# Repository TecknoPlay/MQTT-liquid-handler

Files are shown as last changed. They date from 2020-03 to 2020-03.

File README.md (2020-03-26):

MQTT-liquid-handler
=====
**3D printed and remotely controllable liquid handler (peristaltic pump and syringe)**
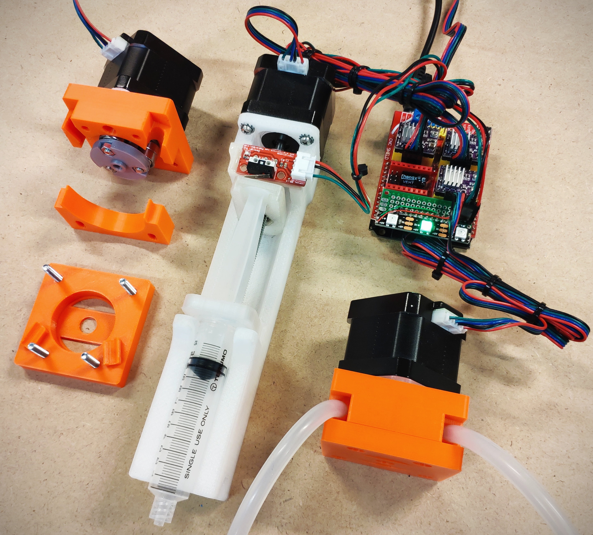
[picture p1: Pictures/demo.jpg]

**Price : around 50€-75€**

Material 
-----
### Electronic 
- ESP32 UNO [Aliexpress](https://www.aliexpress.com/item/32839196190.html) [Amazon](https://www.amazon.fr/ESP32-Carte-Bluetooth-ESP-32-ESP32S/dp/B07FS8FV1K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) 
- Arduino UNO CNC shield (with DRV8825) [Aliexpress](https://www.aliexpress.com/item/32808956717.html) [Amazon](https://www.amazon.fr/dp/B082Y4B6HC/)
- Nema17 [Aliexpress](https://www.aliexpress.com/item/32376023464.html) [Amazon](https://www.amazon.fr/dp/B07CZHLKTC)
- Limit switch [Aliexpress](https://www.aliexpress.com/item/32951447527.html) [Amazon](https://www.amazon.fr/dp/B073XGRRM4)
- CNC Kit [Aliexpress](https://www.aliexpress.com/item/33031649687.html) [Amazon](https://www.amazon.fr/dp/B06Y2BSCL7)
- 12V DC 5.5x2.1mm 

#### Non essential
- PCB [Aliexpress](https://www.aliexpress.com/item/32854111824.html ) 
- WS2812B RGB [Aliexpress](https://www.aliexpress.com/item/32682015405.html) 

### Screws 
**For 1 pumps and 1 syringe**
- 4X : M4 25
- 3x : M4 20
- 7X : M4 hex nuts
- 2X : M3 13
- 1X : M8 threaded rod cut to 70mm
- 1X : M8 hex nut
- 2X : M3 12
- 6x : 4x13x5mm (624ZZ) ball bearing 

Tools 
-----
### Hardware
- 3D Printer
- Phillips screwdriver
- Soldering iron
- Epoxy / glue

### Software
- Arduino IDE
- 3D printer slicer (Slic3r, Cura, ...)

**See WiKi for more instructions**

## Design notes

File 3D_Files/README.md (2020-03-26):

## Print settings
- Suggested filament : PETG (or ABS)
- Infill : 25%
- Layer height : 0.2mm
- Nozzle diameter : 0.4mm
- Support : Only for "Piston Lock" and "Rotor Base"

## Material (1 pump)
- 4X Mx X screw
- 4X Mx nut
- 2X 

## Material (1 syringe)

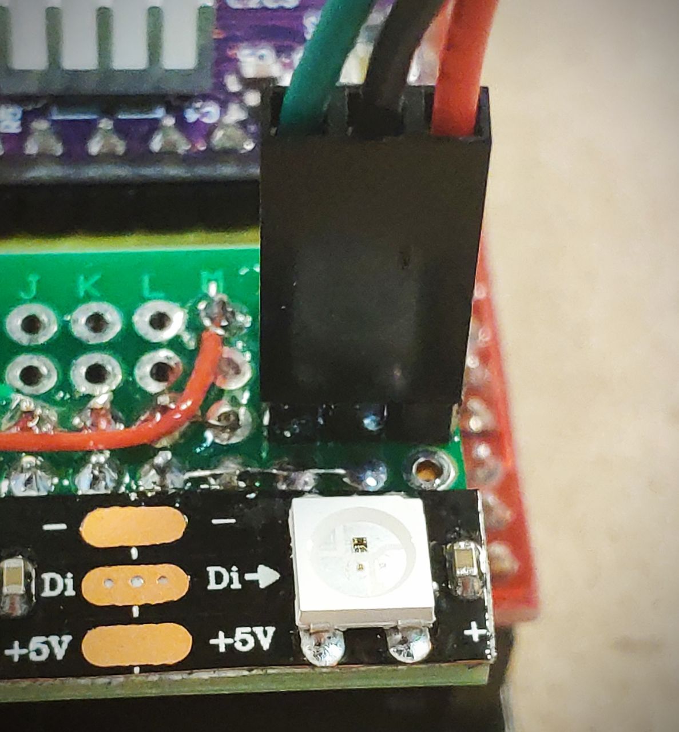
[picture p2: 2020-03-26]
Pictures/endstop_cable.jpg

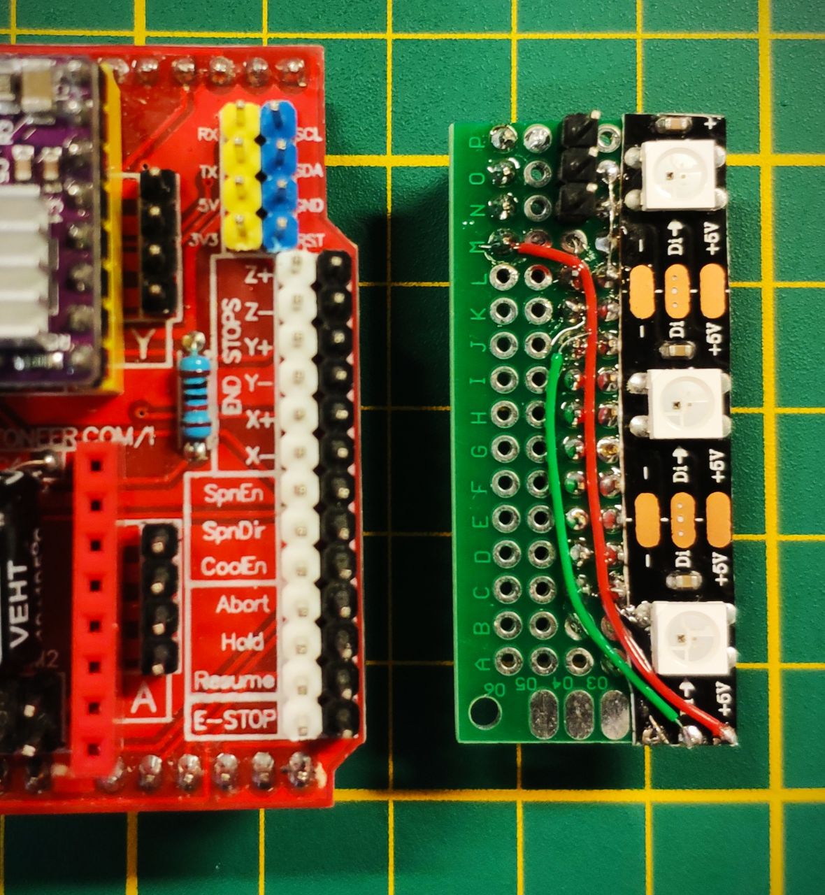
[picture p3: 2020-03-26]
Pictures/led_board.jpg

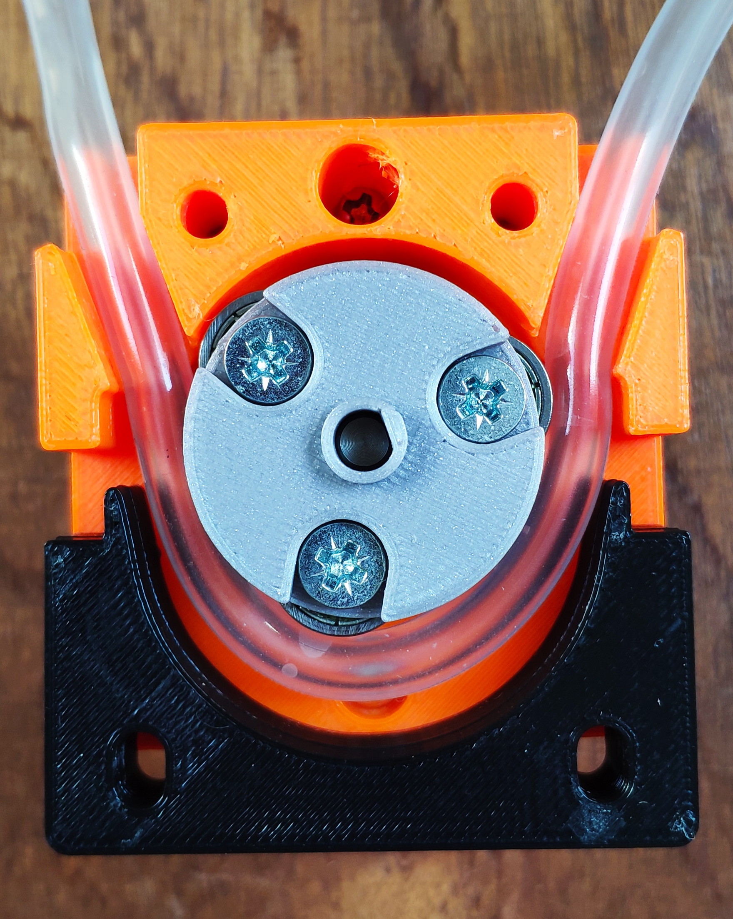
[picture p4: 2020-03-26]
Pictures/stator_C.jpg

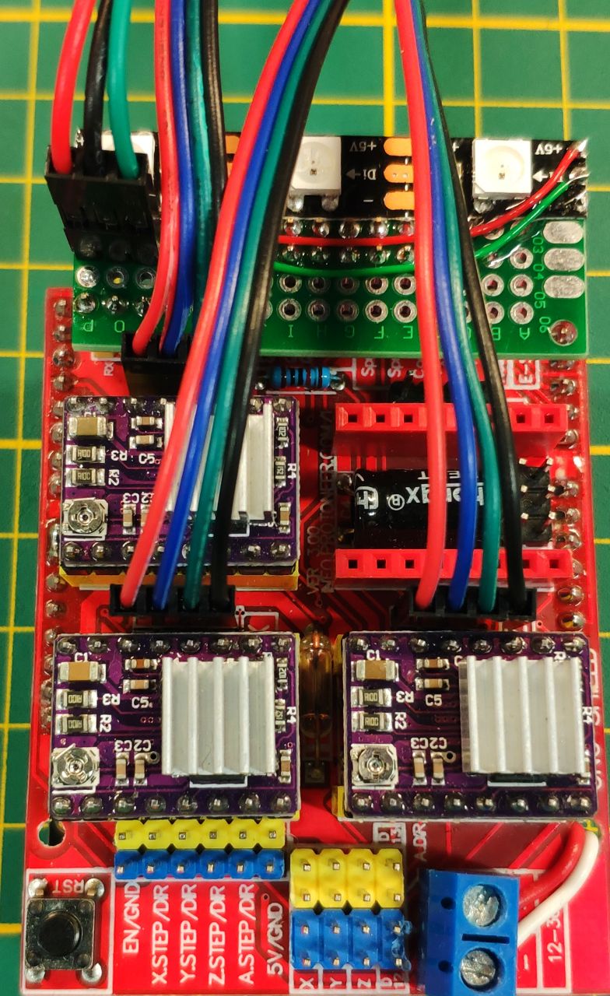
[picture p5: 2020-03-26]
Pictures/cables.jpg

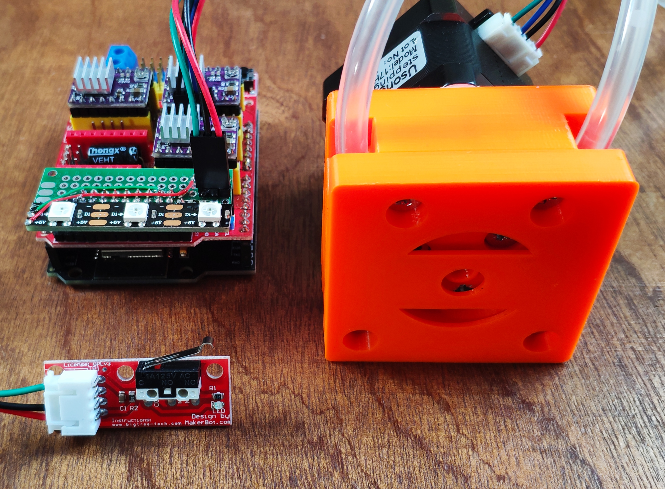
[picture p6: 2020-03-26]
Pictures/ex_pump.jpg

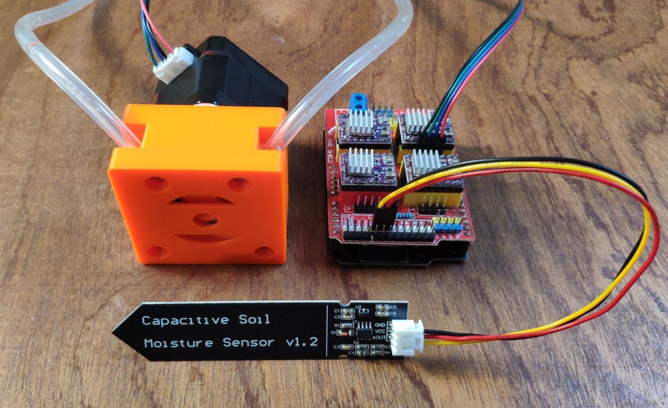
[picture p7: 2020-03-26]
Pictures/humidity_sensor.jpg

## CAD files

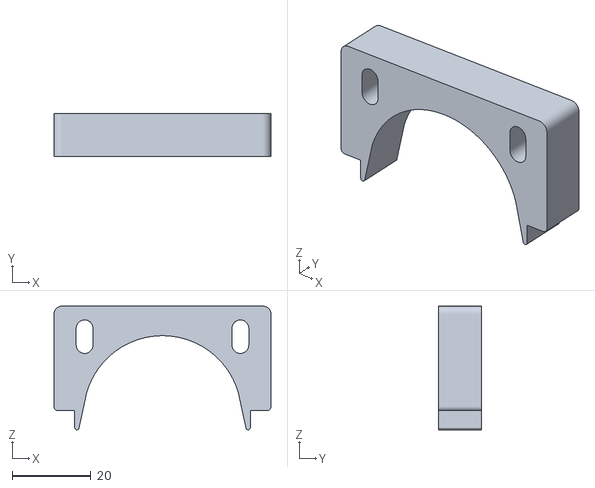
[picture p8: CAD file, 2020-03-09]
3D_Files/7mm_Pump_Lock.stl
55.0 x 11.0 x 31.4

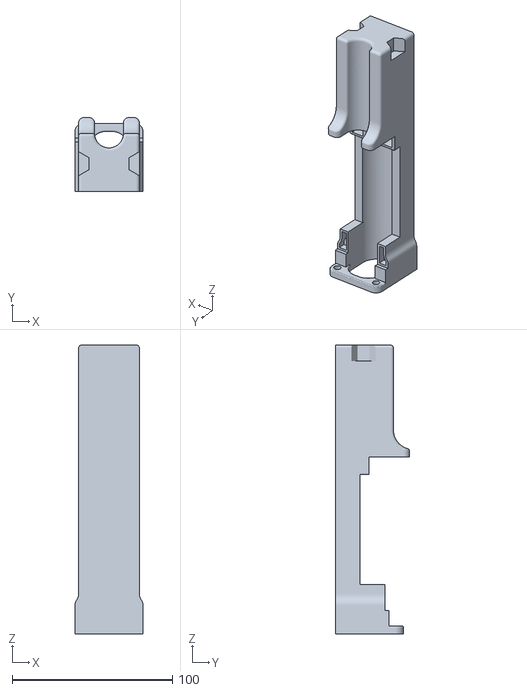
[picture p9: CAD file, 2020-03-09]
3D_Files/Base.stl
42.5 x 46.2 x 180.5

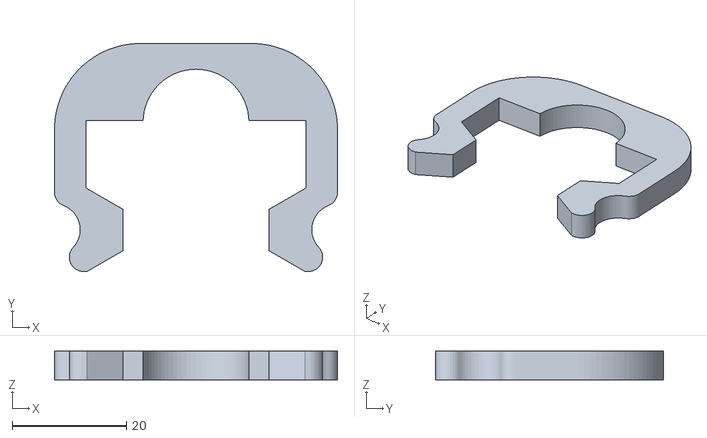
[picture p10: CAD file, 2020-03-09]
3D_Files/Syringe_Lock_B.stl
49.5 x 39.9 x 5.00

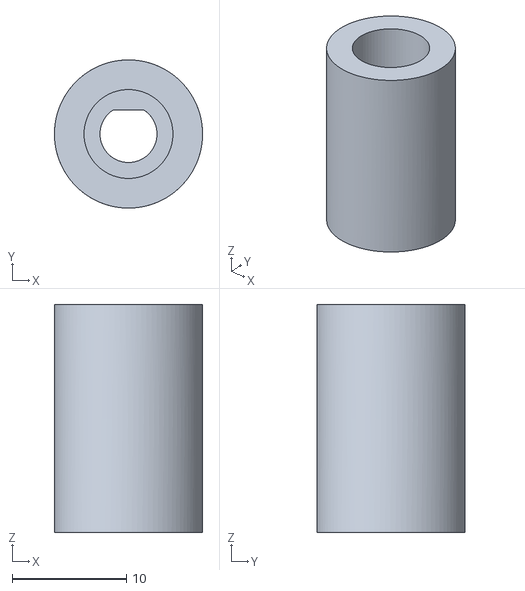
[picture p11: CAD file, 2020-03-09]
3D_Files/Coupler.stl
13.0 x 13.0 x 20.0

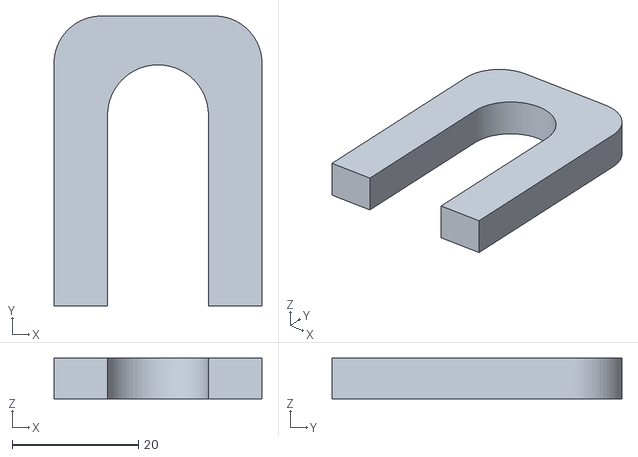
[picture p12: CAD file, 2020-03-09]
3D_Files/Syringe_Lock_A.stl
33.0 x 46.0 x 6.50

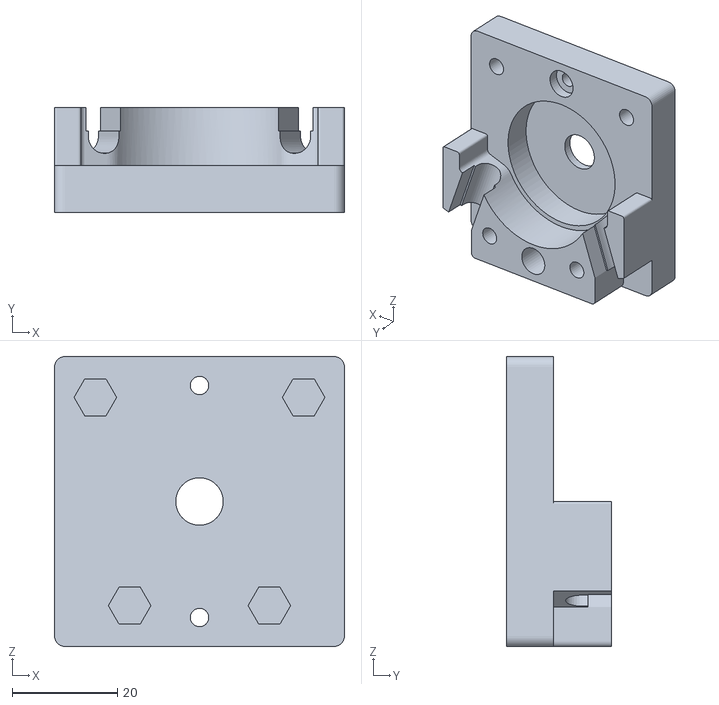
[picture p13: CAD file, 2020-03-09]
3D_Files/7mm_Pump_Base.stl
55.0 x 20.0 x 55.0

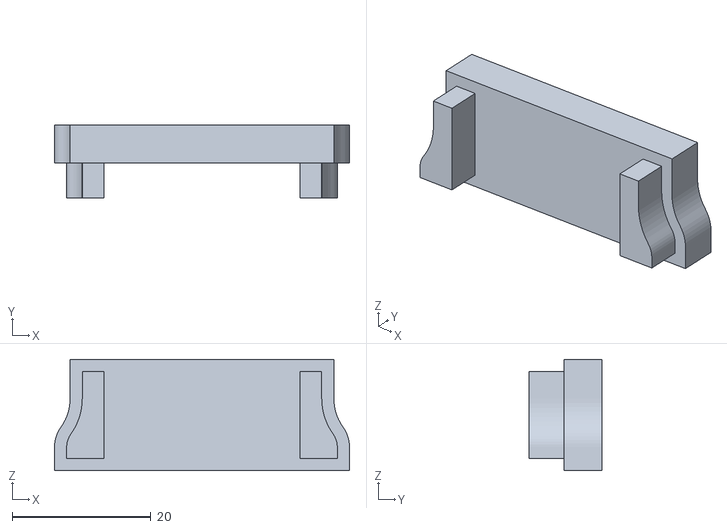
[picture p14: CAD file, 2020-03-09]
3D_Files/Endstop_Support.stl
42.5 x 10.5 x 16.0

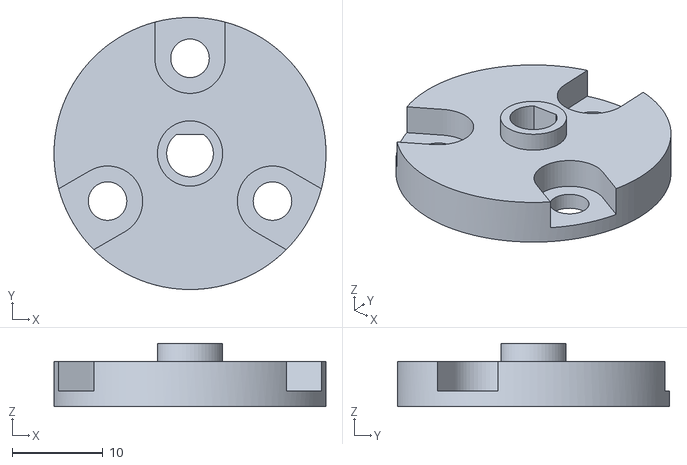
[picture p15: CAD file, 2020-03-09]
3D_Files/Rotor_Top.stl
30.0 x 30.0 x 7.00

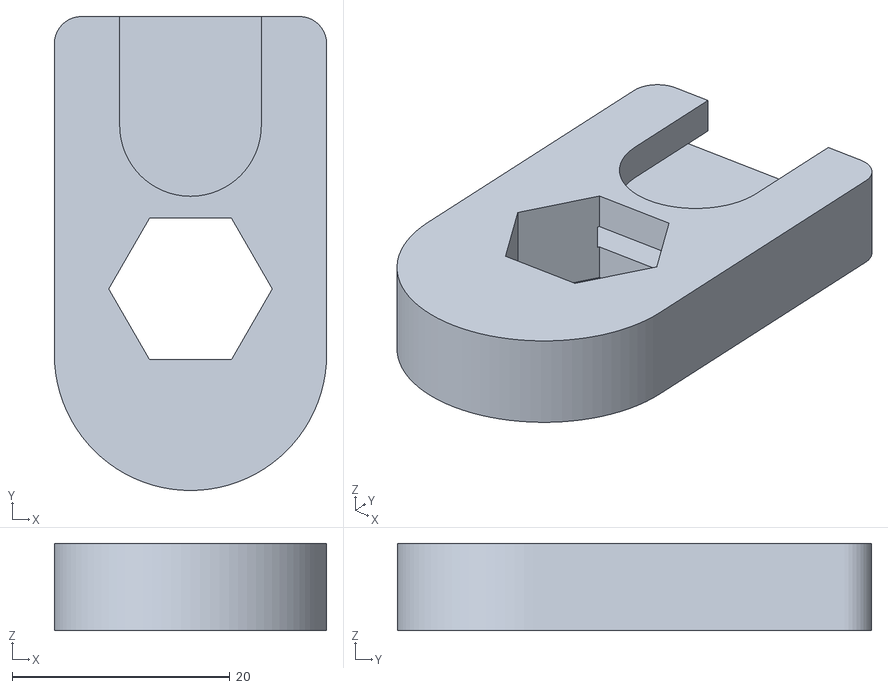
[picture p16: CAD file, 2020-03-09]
3D_Files/Piston_Lock.stl
25.0 x 43.5 x 8.00

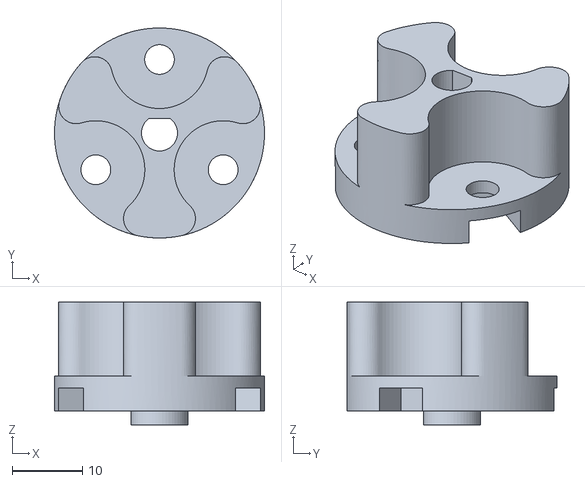
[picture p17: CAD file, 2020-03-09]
3D_Files/Rotor_Base.stl
30.0 x 30.0 x 17.5

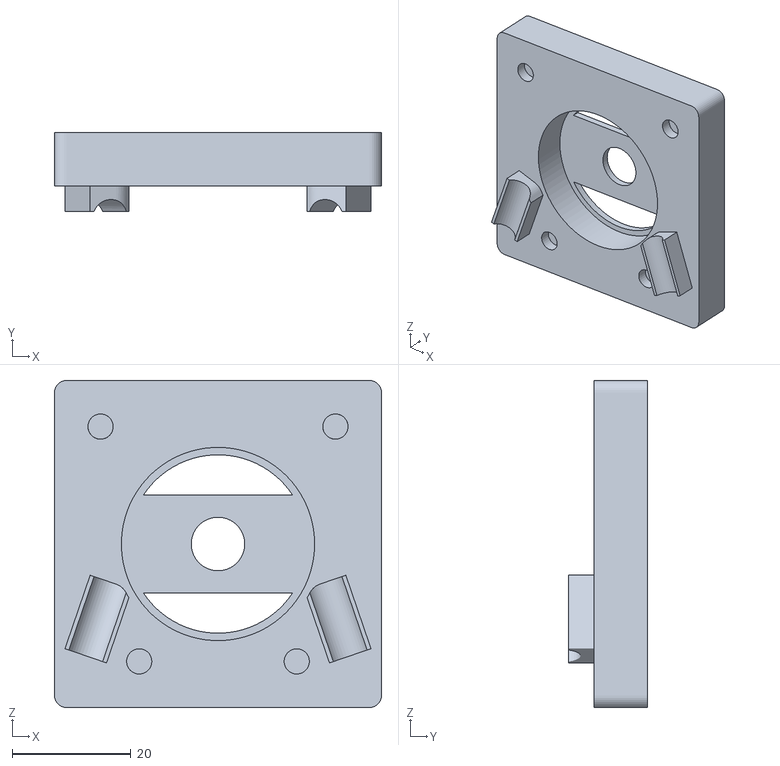
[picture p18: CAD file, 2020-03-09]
3D_Files/7mm_Pump_Top.stl
55.0 x 13.2 x 55.0

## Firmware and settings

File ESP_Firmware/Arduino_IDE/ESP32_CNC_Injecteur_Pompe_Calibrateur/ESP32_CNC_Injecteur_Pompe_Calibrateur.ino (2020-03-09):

//REM : Couper le connecteur de la PIN12 et Jump PIN12 et 13 sur le Shield
#include <Wire.h>
#include <Arduino.h>
#include <ArduinoJson.h> //ArduinoJSON6
#include "SPIFFS.h"
#include <FastLED.h>
//#include "FS.h"
//#include "FFat.h"
#include "time.h"
#include "DRV8825.h" //V1.1.3
long unsigned int PrevMil = 0;
long unsigned int PrevMil2 = 0;
int StepOffDelay = 5000;
int LEDOffDelay = 1000;

DynamicJsonDocument ModulesInfos(2048);
DynamicJsonDocument WiFiJSON(2048);

#include <WiFi.h>
#include <PubSubClient.h>
WiFiClient espClient;
PubSubClient client(espClient);

String SMot = "N";
String Cmd = "0";
volatile bool EndStop = false;

#define NUM_LEDS 3
#define DATA_PIN 5
CRGB leds[NUM_LEDS];

#define ZPLUS 23 //(VSPI MOSI)
#define YPLUS 5 //(VSPI CS0)
#define SPNEN 19 //(VSPI MISO)
#define SPNDIR 18 //(VSPI CLK)
#define COOEN 34 //(InputOnly/RTC_GPIO4/ADC1_CH6)
#define ABORT 2 //(ADC2_CH1/Touch2/RTC_GPIO12)
#define HOLD 4 // (ADC2_CH0/Touch0/RTC_GPIO10)
#define RESUME 35 //(InputOnly/RTC_GPIO5/ADC1_CH7)
#define SDA 39 //(InputOnly/Sensor_VN/RTC_GPIO3/ADC1_CH3)
#define SCL 35 //(InputOnly/RTC_GPIO5/ADC1_CH7)
#define RST 0 //(ADC2_CH1/Touch1/RTC_GPIO11)
//#define LED_BUILTIN 2

//WiFi, MQTT settings
const char *ssid, *password, *mqtt_server, *TopicINFO, *TopicDEBUG, *TopicCONFIG, *TopicCMD, *HostName;
const char* ntpServer = "pool.ntp.org";

#define RPM 200
//MOTOR_STEPS, DIR, STEP, ENABLE, MS1, MS2, MS3
DRV8825 StepperX(200, 16, 26, 13, 0, 0, 0);
DRV8825 StepperY(200, 27, 25, 13, 0, 0, 0);
DRV8825 StepperZ(200, 14, 17, 13, 0, 0, 0);

//Syringe EndStop interrupt (button connected to ZPLus)
void IRAM_ATTR HomeEnd() {
  StepperX.disable();
  EndStop = false;
  StepperX.enable();
  leds[2] = CRGB( 0, 0, 50);
  PrevMil2 = millis() + LEDOffDelay;
}
//SETUP===========================================================
void setup() {
  Serial.begin(9600);
  Serial.println();

  GetConfigModule();
  GetWiFiJSON();
  setup_wifi();
  client.setServer(mqtt_server, 1883);
  client.setCallback(callback);

  configTime(3600, 3600, ntpServer);

  //pinMode(LED_BUILTIN, OUTPUT);
  pinMode(ZPLUS, INPUT_PULLUP);
  attachInterrupt(digitalPinToInterrupt(ZPLUS), HomeEnd, FALLING);
  pinMode(HOLD, OUTPUT);
  pinMode(RESUME, INPUT);
  pinMode(SPNEN, INPUT_PULLUP);

  StepperX.begin(RPM);
  StepperX.enable();
  StepperY.begin(RPM);
  StepperY.enable();
  StepperZ.begin(RPM);
  StepperZ.enable();

  FastLED.addLeds<WS2812, DATA_PIN, GRB>(leds, NUM_LEDS);
}
//SETUP===========================================================

//LOOP============================================================
void loop() {
  if (!client.connected()) {
    reconnect();
  }
  client.loop();
  yield();

  if (millis() - PrevMil > StepOffDelay) {
    PrevMil = millis();
    StepperX.disable();
    StepperY.disable();
    StepperZ.disable();
  }

  if (millis() > PrevMil2) {
    //PrevMil2 = millis();
    leds[0] = CRGB( 0, 0, 0);
    leds[2] = CRGB( 0, 0, 0);
    FastLED.show();
  }
  FastLED.show();

}
//LOOP============================================================

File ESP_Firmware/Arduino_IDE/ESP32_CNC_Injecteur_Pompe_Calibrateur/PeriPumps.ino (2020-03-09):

void PumpCalib(String motor, String calvol) {
  digitalWrite(HOLD, HIGH);
  bool ldr_mode = false;
  int caldiv = 2;
  int tresh = 500;
  int calvol_int = calvol.toInt();
  int calstep = 0;
  int ldr_calib = 0;
  float calval = 0;
  EndStop = true;
  String debug = "Pump" + motor + "calibrated";

  //Check if Calvol is > 10ml
  if (calvol_int < 10) {
    Serial.println("ERROR ! Calibration volume is too small");
    client.publish(TopicDEBUG, "ERROR ! Calibration volume is too small");
    digitalWrite(HOLD, LOW);
    RedLED(0);
    return;
  }

  //Proceed to LDR calibration if ldr_mode == true
  if (ldr_mode == true) {
    //LDR calibration
    Serial.println("LDR calibration");
    for (int i = 0; i < 5; i++) {
      ldr_calib += analogRead(RESUME);
      delay(250);
      Serial.println(ldr_calib);
    }
    ldr_calib = ldr_calib / 5;
    Serial.println("LDR calibrated. Performing pump calibration");
    client.publish(TopicDEBUG, "LDR calibrated. Performing pump calibration");
  }

  while (EndStop == true) {
    OrangeLED(0);
    if (motor == "X") {
      StepperX.enable();
      StepperX.move(200 / caldiv);
    }
    else if (motor == "Y") {
      StepperY.enable();
      StepperY.move(200 / caldiv);
    }
    else if (motor == "Z") {
      StepperZ.enable();
      StepperZ.move(200 / caldiv);
    }
    if (ldr_mode == true) {
      if (analogRead(RESUME) < ldr_calib - tresh) {
        EndStop = false;
      }
    }
    else {
      if (digitalRead(SPNEN) == LOW) {
        EndStop = false;
      }
    }
    calstep += 1;
  }

  GreenLED(0);

  //Calval (in ml/turn) = calvol/(calstep/caldiv)
  calval = float(calvol_int) / (float(calstep) / float(caldiv));
  String output = "Calibration performed. Val = " + String(calval) + "ml/turn";
  Serial.println(output);
  client.publish(TopicDEBUG, output.c_str());
  digitalWrite(HOLD, LOW);

  //Save calval in the memory
  if (motor == "X") {
    ModulesInfos["XC"] = float(calval);
    SaveConfigModule();
  }
  else if (motor == "Y") {
    ModulesInfos["YC"] = float(calval);
    SaveConfigModule();
  }
  else if (motor == "Z") {
    ModulesInfos["ZC"] = float(calval);
    SaveConfigModule();
  }
}

void PumpInject(String motor, float volume) {
  float calval = 0;

  if (motor == "X") {
    calval = ModulesInfos["XC"];
    if (calval < 0) {
      Serial.println("ERROR ! Pump not calibrated");
      client.publish(TopicDEBUG, "ERROR ! Pump not calibrated");
      RedLED(0);
      return;
    }
    else {
      BlueLED(0);
      StepperX.enable();
      StepperX.move((volume / calval) * 200);
    }
  }
  else if (motor == "Y") {
    calval = ModulesInfos["YC"];
    if (calval < 0) {
      Serial.println("ERROR ! Pump not calibrated");
      client.publish(TopicDEBUG, "ERROR ! Pump not calibrated");
      RedLED(0);
      return;
    }
    else {
      BlueLED(0);
      StepperY.enable();
      StepperY.move((volume / calval) * 200);
    }
  }
  else if (motor == "Z") {
    calval = ModulesInfos["ZC"];
    if (calval < 0) {
      Serial.println("ERROR ! Pump not calibrated");
      client.publish(TopicDEBUG, "ERROR ! Pump not calibrated");
      RedLED(0);
      return;
    }
    else {
      BlueLED(0);
      StepperZ.enable();
      StepperZ.move((volume / calval) * 200);
    }
  }
  Serial.println("Done");
  client.publish(TopicDEBUG, "Done");

}
